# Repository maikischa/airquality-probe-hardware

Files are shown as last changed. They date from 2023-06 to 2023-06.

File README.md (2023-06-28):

# Air Quality Probe
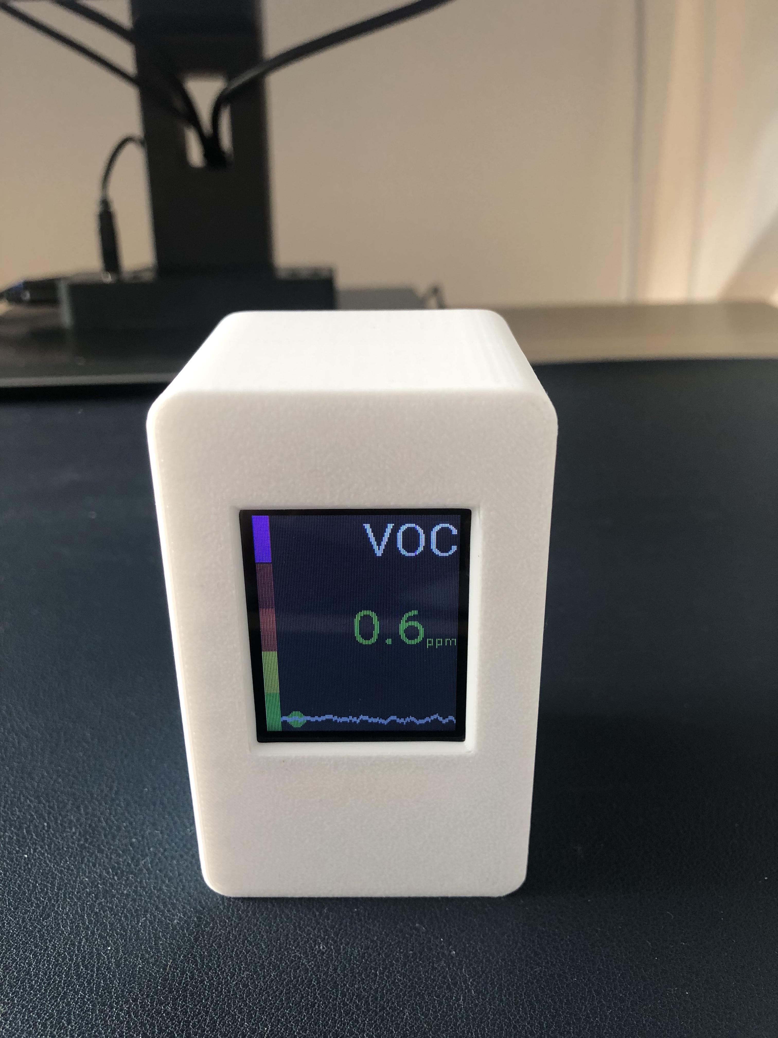
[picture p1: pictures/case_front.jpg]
Front

This DIY Air Quality Sensor measures temperature, humidity, pressure, air quality (IAQ), CO2 and VOC.
The data is visualy represented on a display as well available via [Home Assistant](https://www.home-assistant.io).

# Where to find what?
## case
Here are files related to the housing for the DIY probe. The housing is optimized for 3d printing.
## electronics
Here you find schematics, pcb desings and BOM files.
Firmware can be found in https://github.com/maikischa/airquality-probe-firmware
## pictures
Pictures of the probe

# Hardware
## Air Quality Sensor
This project uses the [Bosch BME 680](https://www.bosch-sensortec.com/products/environmental-sensors/gas-sensors/bme680/) to meassure the airqulity. The housing is designed to hold a [jOY-iT BME 680](https://www.joy-it.net/de/products/SEN-BME680) sensor board.
## Display
I used an ILI9341 TFT LCD Screen. Have a look at [aliexpress](https://www.aliexpress.com/af/Ili9341.html)
## Mainboard
PCB_V0.1
This project uses a custom PCB based on an[ ESP32-WROOM-32E](https://www.espressif.com/sites/default/files/documentation/esp32-wroom-32e_esp32-wroom-32ue_datasheet_en.pdf). All connectors are placed in a way that it fits nicely in the housing.

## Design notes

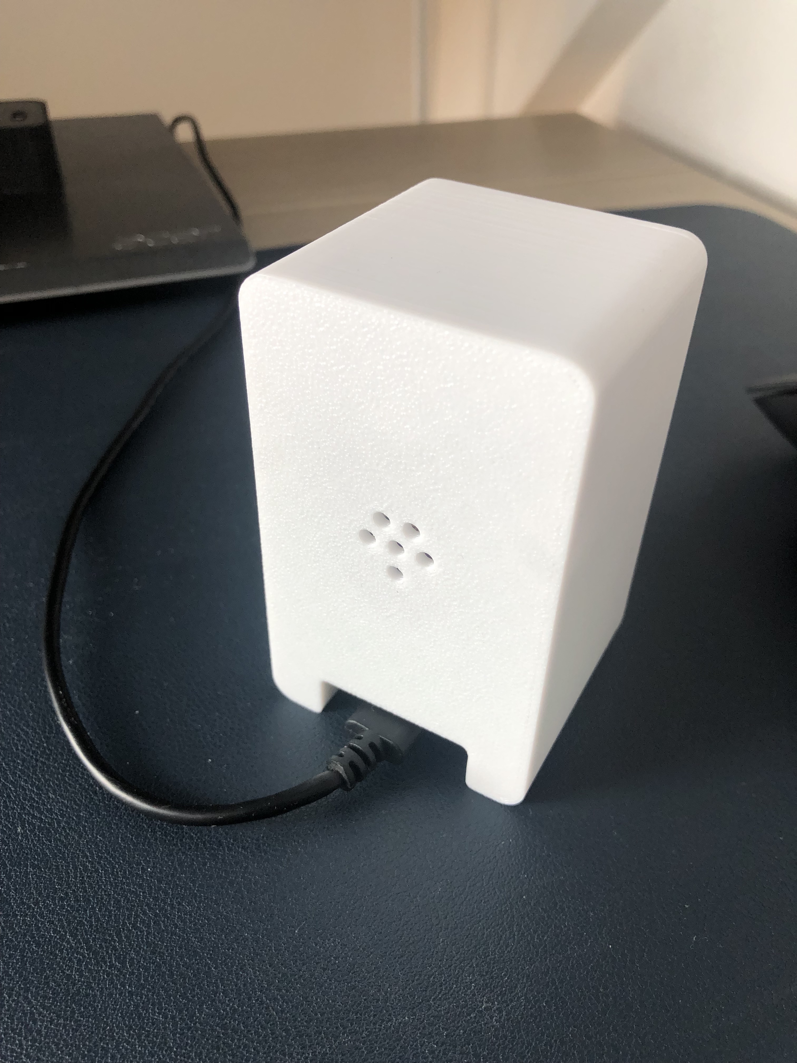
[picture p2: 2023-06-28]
pictures/case_back.jpg

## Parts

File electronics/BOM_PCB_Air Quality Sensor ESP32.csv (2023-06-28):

ID | Name | Designator | Footprint | Quantity | Manufacturer Part | Manufacturer | Supplier | Supplier Part | Price
1 | PM2.54-1*8 | DISPLAY1 | HDR-TH_8P-P2.54-V-F | 1 | PM2.54-1*8 | ZHOURI(洲日) | LCSC | C5224027 | 0.092
2 | TS-1187A-B-A-B | BOOT,RESET | SW-SMD_4P-L5.1-W5.1-P3.70-LS6.5-TL-2 | 2 | TS-1187A-B-A-B | XKB Connectivity(中国星坤) | LCSC | C318884 | 0.016
3 | 15pF | C1 | C0603 | 1 | CL10C150JB8NNNC | SAMSUNG(三星) | LCSC | C1644 | 0.005
4 | 4.7uF | C2 | C0603 | 1 | CL10A475KO8NNNC | SAMSUNG(三星) | LCSC | C19666 | 0.01
5 | 100nF | C3,C7,C10 | C0603 | 3 | CC0603KRX7R9BB104 | YAGEO(国巨) | LCSC | C14663 | 0.002
6 | 22uF | C4,C5,C6 | C0805 | 3 | CL21A226MAQNNNE | SAMSUNG(三星) | LCSC | C45783 | 0.025
7 | 600Ω | L1 | L0603 | 1 | GZ1608D601TF | Sunlord(顺络) | LCSC | C1002 | 0.005
8 | SS8050-G | Q1,Q2 | SOT-23-3_L2.9-W1.6-P1.90-LS2.8-BR | 2 | SS8050-G | CJ(江苏长电/长晶) | LCSC | C164886 | 0.02
9 | 5.1kΩ | R1,R2,R10 | R0603 | 3 | 0603WAF5101T5E | UNI-ROYAL(厚声) | LCSC | C23186 | 0.001
10 | 1MΩ | R3 | R0603 | 1 | 0603WAF1004T5E | UNI-ROYAL(厚声) | LCSC | C22935 | 0.001
11 | 22.1kΩ | R4 | R0603 | 1 | 0603WAF2212T5E | UNI-ROYAL(厚声) | LCSC | C25961 | 0.001
12 | 47kΩ | R5 | R0603 | 1 | 0603WAF4702T5E | UNI-ROYAL(厚声) | LCSC | C25819 | 0.001
13 | 2kΩ | R6 | R0603 | 1 | 0603WAF2001T5E | UNI-ROYAL(厚声) | LCSC | C22975 | 0.001
14 | 10kΩ | R7,R8,R9,R11 | R0603 | 4 | 0603WAF1002T5E | UNI-ROYAL(厚声) | LCSC | C25804 | 0.001
15 | 1125-1104G0S118C005 | SENSOR1 | HDR-TH_4P-P2.54-V-M | 1 | 1125-1104G0S118C005 | Wcon(维峰电子) | LCSC | C721444 | 0.042
16 | SRV05-4-P-T7 | TV1 | SOT-23-6_L2.9-W1.6-P0.95-LS2.8-BR | 1 | SRV05-4-P-T7 | PROTEK | LCSC | C85364 | 0.176
17 | ESP32-WROOM-32E(4MB) | U1 | WIFI-SMD_ESP32-WROOM-32E | 1 | ESP32-WROOM-32E-N4 | ESPRESSIF(乐鑫) | LCSC | C701341 | 3.416
18 | CP2102-GMR | U2 | WQFN-28_L5.0-W5.0-P0.50-BL-EP3.2 | 1 | CP2102-GMR | SILICON LABS(芯科) | LCSC | C6568 | 2.213
19 | AMS1117-3.3 | U3 | SOT-223-3_L6.5-W3.4-P2.30-LS7.0-BR | 1 | AMS1117-3.3 | AMS | LCSC | C6186 | 0.138
20 | GT-USB-7038A | USB1 | USB-C-TH_G-SWITCH_GT-USB-7038X | 1 | GT-USB-7038A | G-Switch(品赞) | LCSC | C2982474 | 0.404
21 | 0805G (Green) | LED1 | LED0805-R-RD | 1 | KT-0805翠绿 | KENTO | LCSC | C2297
22 | SOLDERJUMPER-OLDNC | SJ1 | SJ_2S | 1
23 | PH-00342 | IO2,IO4 | HDR-TH_2P-P2.54-V-M | 2 | PH-00342 | Liansheng(连盛) | LCSC | C2685154 | 0.034

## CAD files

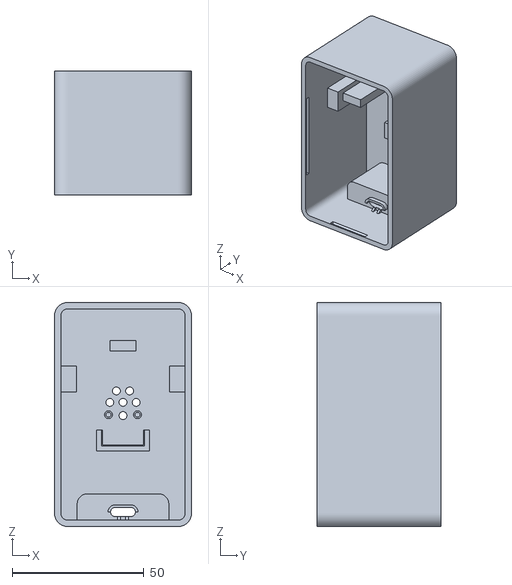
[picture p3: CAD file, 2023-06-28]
case/base.stl
52.0 x 47.0 x 85.0

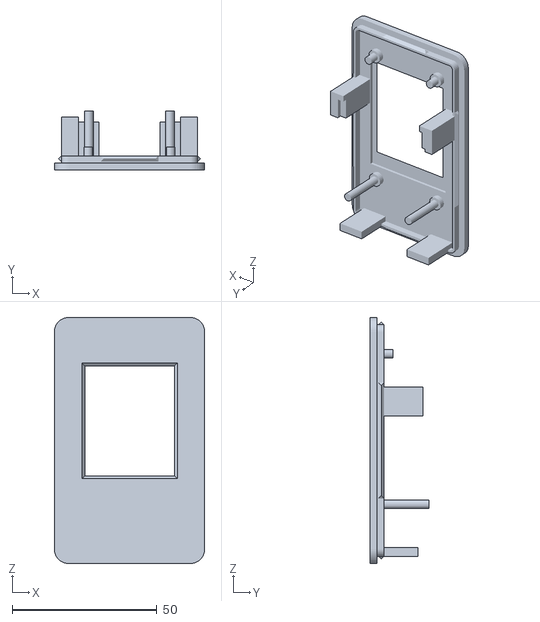
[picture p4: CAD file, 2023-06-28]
case/lid.stl
52.0 x 20.4 x 85.0

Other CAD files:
case/case.f3z

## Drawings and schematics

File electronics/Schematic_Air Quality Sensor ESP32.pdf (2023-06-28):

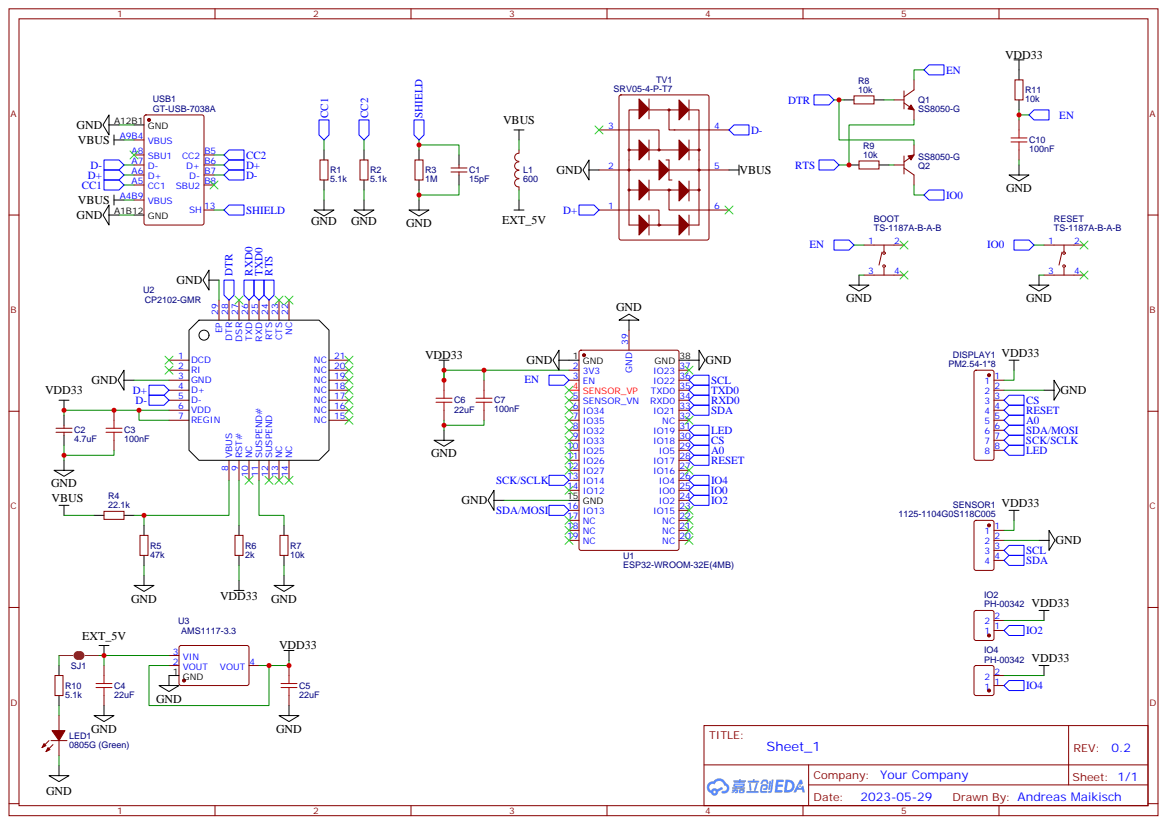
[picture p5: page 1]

NC 22 CTS 23 RTS 24 RXD 25 TXD 26 DSR 27 DTR 28 EP 29

Drawn By: Andreas Maikisch
